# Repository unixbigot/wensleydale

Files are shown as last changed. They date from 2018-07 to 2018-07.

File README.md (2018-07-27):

# Wensleydale - A cabinet for 3D printers and CNC machines

# What, why?

In winter, my FDM 3D printers give poor results due to inability to
keep the part warm.    Also, my CNC mill is REALLY LOUD.

So I wanted a cabinet to cut down heat loss and/or noise.

A friend asked could I make a kit, so I wrote a program to generate 
a parts list at any size.

I wanted to name the project after the robot antagonist in "A Grand
Day Out" but I discovered it was unnamed.   So I made up a name.

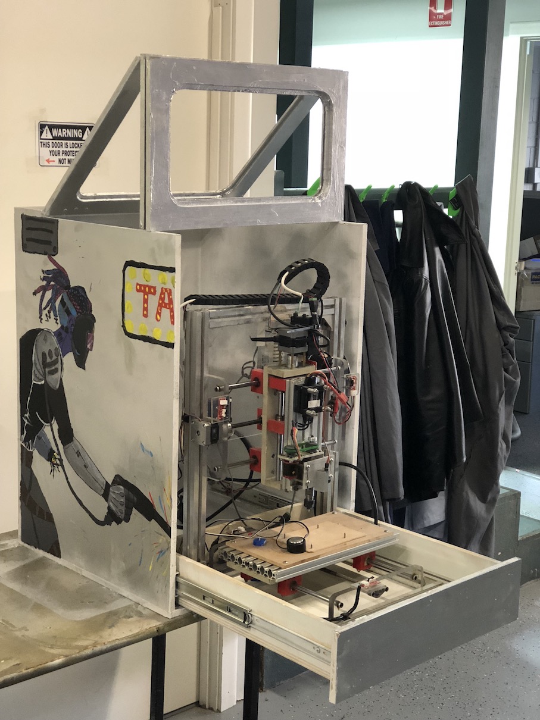
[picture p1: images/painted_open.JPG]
Cabinet side view, with open drawer


# How to make your cabinet

Enter your sizes into the SCAD file, and render the drawing.

The console window will now contain instructions for cutting and
routing your pieces.

Consult the assembled view and attached photographs for instructions.

A brad nailer and PVA glue works well.   Nails or screws work too.

It's possible to make the cabinet with just a jigsaw, drill and
router. A table saw or other circular saw makes it painless.

If you have a CNC router that can cut plywood or MDF, then you 
could use that.

Artwork by my son, Jack Fletcher.

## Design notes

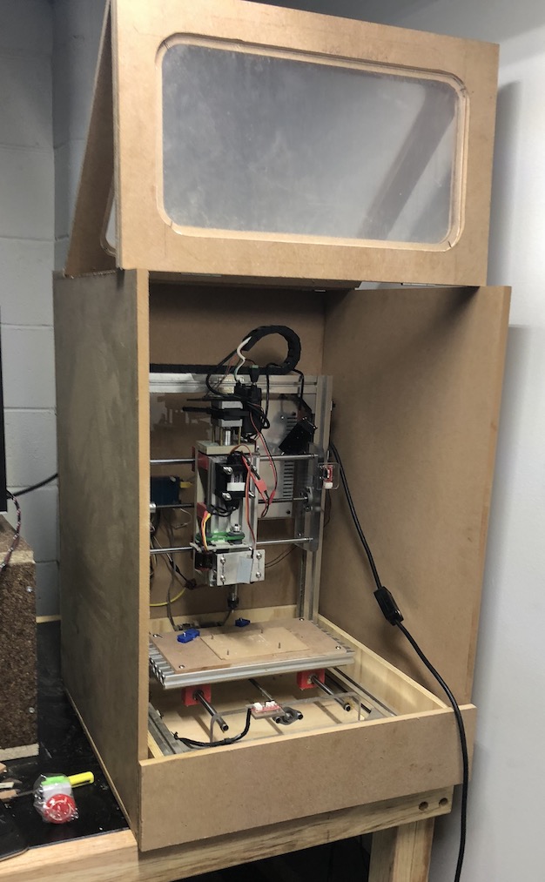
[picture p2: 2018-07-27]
images/unpainted_open.JPG

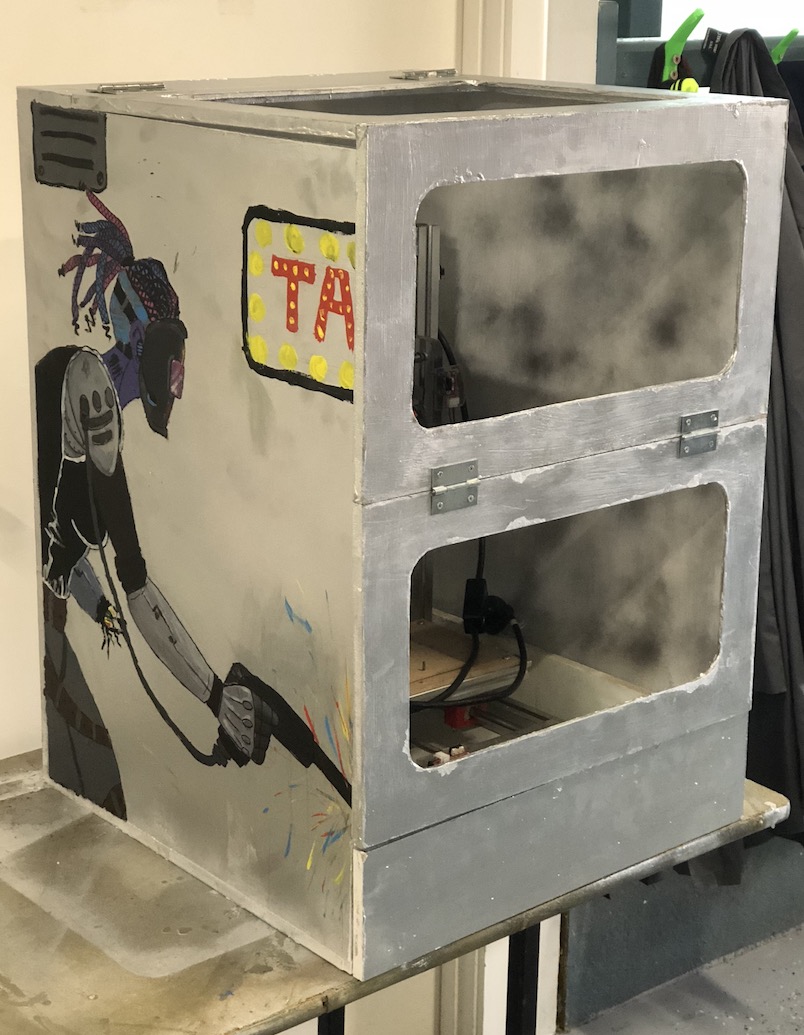
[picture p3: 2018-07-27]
images/painted_closed.JPG

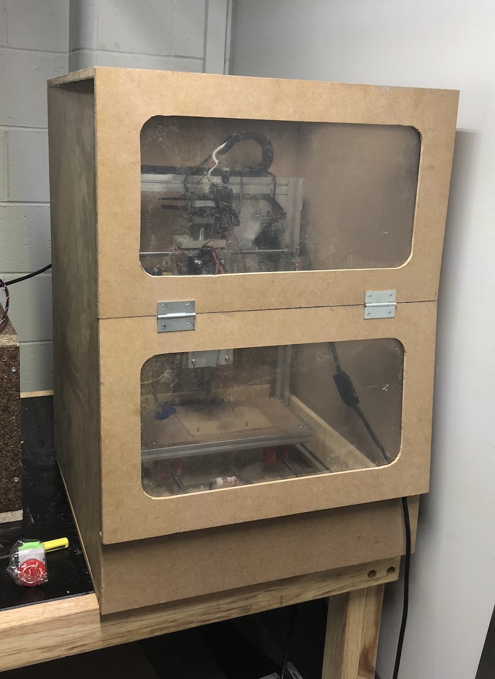
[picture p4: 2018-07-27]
images/unpainted_closed.JPG

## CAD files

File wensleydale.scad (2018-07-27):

// Alter these first four values to change the size and
// thickness of your cabinet.
//
// Note: Dimensions are INTERNAL, that is, your cabinet will
// be this big INSIDE.   It will be bigger by twice the thickness
// on the outside.   Sorry, no Time Lord technology in use here.
//
// Default size fits a Wanhao Duplicator i3 plus
// For a Tronxy X3A: 600,600,600
// For a Tranxy X5-400: 800, 700, 700, thickness=18

width = 500;
depth = 500;
height = 700;
thickness = 12;

// Only change the below if you want to change the proportions
// of the windows and drawer
//
top = depth / 5;
border = 50;
borderradius = border/2;
windowrebate=10;

drawer_thickness = 12;
drawer_height = 120;

// You should only need to change the drawer border if
// you are not using standard ballbearing drawer slides

drawer_side_border = 25;
drawer_bottom_border = 20;
drawer_top_border = 10;

// You should not need to change anything beyond here

topwindow_width = width+2*thickness;
topwindow_depth = depth+thickness-top;

frontwindow_width = width+2*thickness;
frontwindow_depth = (height+2*thickness-drawer_height)/2;

fuzz = 0.4;

module piece(w, d, name) {
    echo(str("  Cut one ", name, " piece ", w, " wide by ", d, " deep."));
    cube([w,d,thickness]);
    translate([w/2, d/2, thickness+fuzz]) color("blue") { //linear_extrude(height=50) { 
        text(text=name, 
            halign="center", valign="center",
            size=50,
            font="Avenir Next Condensed:style=Demi Bold"
        ); 
    }
}

module base() {
    piece(width+2*thickness, depth+thickness, "base");
}
//base();

module back() {
    piece(width+2*thickness, height, "back");
}
//back();

module side() {
    piece(depth, height, "side");
}
//side();

module top() {
    piece(width+2*thickness, top, "top rail");
}
//top();

module window(w, d, name) {
    c = border + borderradius; // center offset
    rr = borderradius+windowrebate; //rebate radius
    rc = border + borderradius - windowrebate; // rebate center offset

    difference() {
        piece(w, d, str(name, " window"));
        echo(str("   Drill four ", 2*borderradius, " dia holes centered ", c, " in from the edges."));
        echo(str("   Join the four holes with a jigsaw, then use a router to cut a ", windowrebate, " mm rebate (or rabbet if are Amerikanski)."));
        hull() {
            translate([c, c,-fuzz]) cylinder(r=borderradius, h=thickness+2*fuzz);
            translate([w-c,c,-fuzz]) cylinder(r=borderradius, h=thickness+2*fuzz);
            translate([c,d-c,-fuzz]) cylinder(r=borderradius, h=thickness+2*fuzz);
            translate([w-c,d-c,-fuzz]) cylinder(r=borderradius, h=thickness+2*fuzz);
        }
        hull() {
            translate([rc, rc,-fuzz]) cylinder(r=rr, h=thickness/2+fuzz);
            translate([w-rc,rc,-fuzz]) cylinder(r=rr, h=thickness/2+fuzz);
            translate([rc,d-rc,-fuzz]) cylinder(r=rr, h=thickness/2+fuzz);
            translate([w-rc,d-rc,-fuzz]) cylinder(r=rr, h=thickness/2+fuzz);
        }
    }
}

module topwindow() {
    window(topwindow_width, topwindow_depth, "top");
}
//topwindow();

module frontwindow() {
    window(frontwindow_width, frontwindow_depth, "front");
}

module drawerfalsefront() {
    piece(width+2*thickness, drawer_height, "drawer false front");
}

module drawerbase() {
    piece(width-2*drawer_side_border, depth-drawer_thickness, "drawer base");
}

module drawerside() {
    piece(depth-drawer_thickness, drawer_height-drawer_top_border-drawer_thickness-drawer_bottom_border, "drawer side");
}

module drawerfrontback(name) {
    piece(width-2*drawer_side_border-2*drawer_thickness, drawer_height-drawer_top_border-drawer_thickness-drawer_bottom_border, str("drawer ",name));
}

module drawer_assembled() {
    drawerbase();
    translate([drawer_thickness, drawer_thickness, drawer_thickness]) rotate([90,0,0]) color("orange") drawerfrontback("front");
    translate([drawer_thickness, depth-drawer_thickness, drawer_thickness]) rotate([90,0,0]) color("black") drawerfrontback("back");
    translate([0, 0, drawer_thickness]) rotate([90,0,90]) color("yellow") drawerside();
    translate([width-2*drawer_side_border-drawer_thickness, 0, drawer_thickness]) rotate([90,0,90]) color("red") drawerside();
}


module assembled() {
    base();
    translate([0,depth+thickness, thickness]) rotate([90,0,0]) color("black") back();
    translate([0,0,thickness]) rotate([90,0,90]) color("yellow") side();
    translate([width+thickness,0,thickness]) rotate([90,0,90]) color("red") side();
    translate([0, depth+thickness-top, height+thickness]) color("blue") top();
    translate([0, 0, height+thickness]) color("cyan") topwindow();
    translate([0, 0, 0]) rotate([90,0,0]) color("orange") drawerfalsefront();
    translate([0, 0, drawer_height]) rotate([90,0,0]) color("magenta") frontwindow();
    translate([0, 0, drawer_height+frontwindow_depth]) rotate([90,0,0]) color("green") frontwindow();

    translate([-width-drawer_height, 0, 0]) drawer_assembled();
}
//assembled();

module parts() {
    g = 4*thickness; // gap
    base();
    translate([width+g,0,0]) side();
    translate([width+g+depth+g,0,0]) side();
    translate([0, depth+g, 0]) back();
    translate([0, depth+g+height+g, 0]) top();
    translate([width+g,height+g,0]) topwindow();
    translate([width+g,height+g+topwindow_depth+g,0]) drawerfalsefront();
    translate([width+g+depth+g,0,0]) side();
    translate([width+g+depth+g, height+g]) {
        frontwindow();
        translate([0,frontwindow_depth+g,0]) frontwindow();
    }

    do = width+g+depth+g+width+g; // drawer offset
    translate([do,0,0]) drawerbase();
    translate([do,depth+g,0]) drawerfrontback("front");
    translate([do,depth+g+drawer_height,0]) drawerfrontback("back");
    translate([do,depth+g+2*drawer_height,0]) drawerside("");
    translate([do,depth+g+3*drawer_height,0]) drawerside("");

//    translate([drawer_thickness, depth-drawer_thickness, drawer_thickness]) rotate([90,0,0]) color("black") drawerfrontback("back");
//    translate([0, 0, drawer_thickness]) rotate([90,0,90]) color("yellow") drawerside();
//    translate([width-2*drawer_side_border-drawer_thickness, 0, drawer_thickness]) rotate([90,0,90]) color("red") drawerside();

}

echo("");
echo("PARTS LIST STARTS HERE");
echo(str("To make cabinet with internal dimensions ", width, " wide by ", depth, " deep by ", height, " tall:"));
translate([-width-drawer_height,0,0]) assembled();
echo("PARTS LIST ENDS HERE");
echo("");
echo("(ignore further instructions)");

parts();
